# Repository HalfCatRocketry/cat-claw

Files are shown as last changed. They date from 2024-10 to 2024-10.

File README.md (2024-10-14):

Cat Claw is a cable cutter mechanism made of modified off-the-shelf commercially available parts. It is designed to be a low-cost and easy to service solution for parachute release to make single-compartment dual deployment recovery widely accessible.
Half Cat Rocketry provides the following:

• Component Guidebook (HCR-4100)

• SolidWorks CAD files (.sldprt)

• 3D models of printed components (.stl)

It is assumed that the reader is familiar with high-power rocketry and the use of basic hand tools.

Please note that the SolidWorks CAD was created in the version 2022 student edition and is for educational purposes.

Half Cat Rocketry is not liable for the usage of this content, and the authors bear no responsibility for the usage of its content. Read the following disclaimer before continuing.

DISCLAIMER:

By viewing, downloading, printing, or otherwise possessing the content in this repository you agree to the terms and conditions of its use, which are provided below. If you do not agree to the terms and conditions, you are required to remove this content from your possession by deleting all digital copies and/or disposing of printed materials in an environmentally responsible manner. Failure to do so shall constitute a violation of the license under which this content is distributed.

This content is provided as is, with absolutely NO WARRANTY, express or implied, including no warranty of merchantability or fitness for any particular purpose. You (“the user”) agree by your continued viewing or possession of this content to hold harmless and release from all liability the authors and any associated parties for any outcome resulting from your use or misuse of this material. The authors bear no responsibility for the usage of the this content, and any and all liability for injury, property damage, financial loss, death, or other harm arising from its use or misuse rests solely with the user.

This content is provided solely for informational and entertainment purposes and does not constitute an endorsement of, nor a recommendation to engage in, any particular activity, method, or practice. The information contained in this content solely represents the personal experiences of the authors and does not promise, guarantee, or predict any specific outcome of any particular activity, method, or practice.

The user acknowledges by continued viewing or possession of this content that rocketry and all associated activities, including but not limited to the procurement, manufacture, assembly, disassembly, modification, storage, handling, transport, operation, testing, launching, recovery and disposal of rocket and rocket motor systems, components, propellants, and accessories are inherently dangerous and may pose a direct and immediate hazard to health, life, and property.

Mentions of any particular products within this content by part number, name, description, brand, chemical formula, or any other identifier DO NOT constitute an endorsement of said products, nor is any warranty of merchantability or fitness for any particular purpose of said products expressed or implied by the authors of this content. Should the user purchase any product mentioned, listed, or otherwise discussed in this content, the user is solely responsible for determining the suitability of any and all products for the user’s specific application. The user is solely responsible for any outcome or liability arising from the use or misuse of any products named, described, or otherwise alluded to in this content.

As stated above, your (“the user’s”) continued viewing or possession of the content in this repository constitutes acknowledgement of and agreement to these warnings, terms, and conditions. If you do not agree to these terms and conditions, or do not wish to acknowledge the warnings provided herein, you are required to remove this content from your possession by deleting all digital copies and/or disposing of printed materials in an environmentally responsible manner. Failure to do so shall constitute a violation of the license under which this content is distributed.

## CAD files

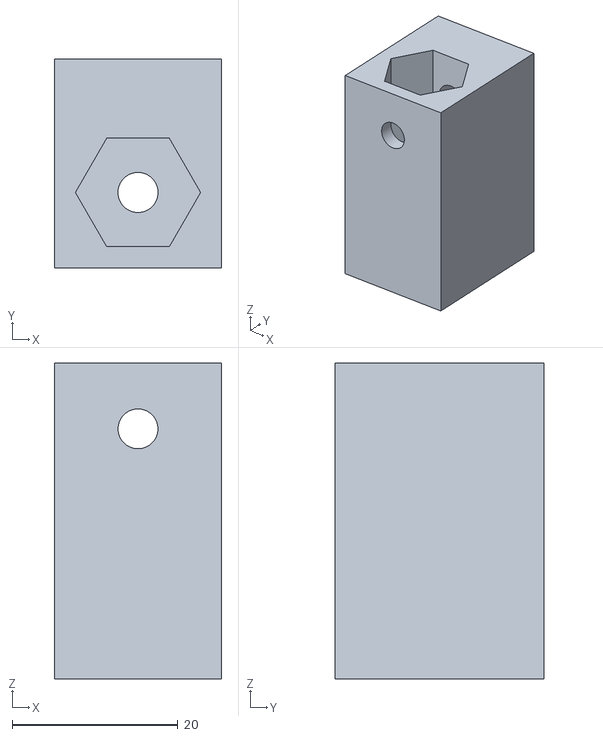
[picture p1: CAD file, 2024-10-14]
Printed Components/Cat Claw Drill Jig.STL
20.2 x 25.1 x 38.1

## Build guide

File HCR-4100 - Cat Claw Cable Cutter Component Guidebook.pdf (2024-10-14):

# Cat Claw Cable Cutter

# Component Guidebook

# HCR-4100

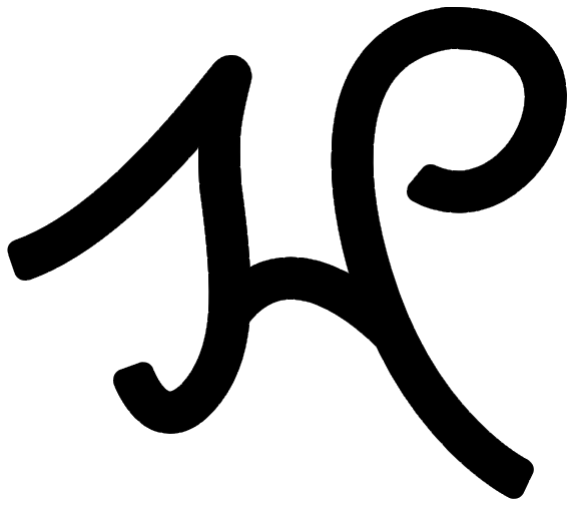
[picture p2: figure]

# Authored by Austin Sennott and Charles Sharp

# Warning

Rockets are dangerous! This publication is intended to provide information on the safe construction and operation of an amateur liquid rocket component, but it is no guarantee of safety. Always follow relevant safety guidelines and best practices when handling hazardous substances or situations – never assume that any situation is inherently safe.Half Cat Rocketry is not liable for the usage of this document, and the authors bear no responsibility for the usage of its content. Read the disclaimer on the next page before continuing.

# License

This guidebook, as well as all information within, is published open source under the GNU General Public License. See last page for more information.

# Attributions

The information contained herein is based upon publicly available content, including textbooks, scientific papers, government publications, and prior art.

All content in this document was written by humans, and not by AI.

Copyright 2024 Half Cat Rocketry

### READ THIS BEFORE CONTINUING

Disclaimer:

By downloading, printing, or otherwise possessing this content you agree to the terms and conditions of its use, which are provided below. If you do not agree to the terms and conditions, you are required to remove this content from your possession by deleting all digital copies and/or disposing of printed materials in an environmentally responsible manner. Failure to do so shall constitute a violation of the license under which this content is distributed.

This document is provided as is, with absolutely NO WARRANTY, express or implied, including no warranty of merchantability or fitness for any particular purpose. You (“the user”) agree by your continued possession of this document to hold harmless and release from all liability the authors and any associated parties for any outcome resulting from your use or misuse of this material. The authors bear no responsibility for the usage of the content of this document, and any and all liability for injury, property damage, financial loss, death, or other harm arising from its use or misuse rests solely with the user.

This document is provided solely for informational and entertainment purposes and does not constitute an endorsement of, nor a recommendation to engage in, any particular activity, method, or practice. The information contained in this document solely represents the personal experiences of the authors and does not promise, guarantee, or predict any specific outcome of any particular activity, method, or practice.

The user acknowledges by continued possession of this content that rocketry and all associated activities, including but not limited to the procurement, manufacture, assembly, disassembly, modification, storage, handling, transport, operation, testing, launching, recovery and disposal of rocket and rocket motor systems, components, propellants, and accessories are inherently dangerous and may pose a direct and immediate hazard to health, life, and property.

Mentions of any particular products within this document by part number, name, description, brand, chemical formula, or any other identifier DO NOT constitute an endorsement of said products, nor is any warranty of merchantability or fitness for any particular purpose of said products expressed or implied by the authors of this document. Should the user purchase any product mentioned, listed, or otherwise discussed in this document, the user is solely responsible for determining the suitability of any and all products for the user’s specific application. The user is solely responsible for any outcome or liability arising from the use or misuse of any products named, described, or otherwise alluded to in this document.

As stated above, your (“the user’s”) continued possession of this document constitutes acknowledgement of and agreement to these warnings, terms, and conditions. If you do not agree to these terms and conditions, or do not wish to acknowledge the warnings provided herein, you are required to remove this content from your possession by deleting all digital copies and/or disposing of printed materials in an environmentally responsible manner. Failure to do so shall constitute a violation of the license under which this content is distributed.

# About Half Cat Rocketry

Half Cat Rocketry began as a project to build a liquid bipropellant rocket in our final undergraduate semester at the University of Central Florida. From September through December 2020, we constructed, iterated, and finally test fired Half Cat Walking. From participating in introductory rocket projects, to leading them, to producing solid motors, to designing hybrid systems, four years of learning culminated in four months of innovation and success.

We are Austin Sennott and Charles Sharp. For eight years, we have been relentlessly gaining experience in amateur rocketry, woven together with education and careers in aerospace engineering. Today, our focus is on pioneering simple, reliable liquid rocket motors and supporting students and individuals looking to build their own. Our goal is to demonstrate that they can be accomplished quickly and economically, for the benefit of both the hobby and the careers of students everywhere. We were once students ourselves, and still produce rockets with our own time and money, so we are well acquainted with the need to reduce scope and budget as much as possible.

Half Cat is the name of a meme, unique and recognizable. We do serious work, but we don't take ourselves too seriously - our brand and project names are a lighthearted nod to the industry, which can too often lack originality.

Half Cat Rocketry is ongoing, and we will continue to build rockets and publish

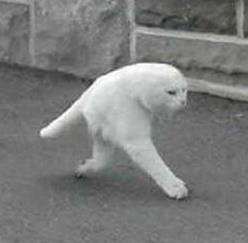
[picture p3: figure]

information about them. Our hope is to redefine what's possible for students and amateurs to achieve with a little bit of creativity, leading the way for ever more awesome projects.

# About the Authors

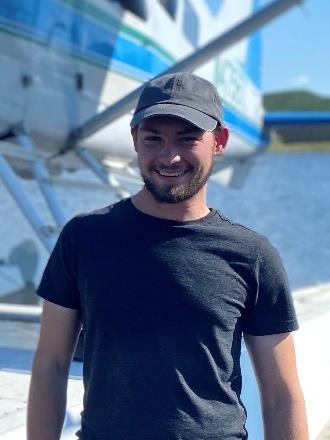
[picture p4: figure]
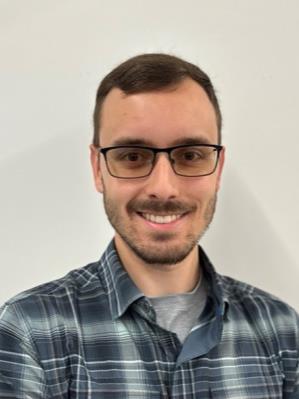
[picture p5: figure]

Austin Sennottis a
rocket propulsion
engineer and Level 2
certified in high-power
rocketry. Since 2018, he
has been building
experimental solid,
hybrid, and liquid
motors, including the
first liquid bipropellant
rocket fired at UCF.

LinkedIn (https://www.linkedin.com/in/austinsennott/)

Charles Sharp is Level
3 certified in high-power
rocketry and employed
as a rocket propulsion
engineer. In over 10 years of building rockets, he
has gained expertise in
all types of rocket
propulsion, including the
first high-power rocket
propelled by liquid CO2.

LinkedIn (https://www.linkedin.com/in/charlessharpengineer/)

## CAT CLAW | Component Guidebook | HCR-4100

Half Cat Rocketry
HalfCatRocketry.com
contact@halfcatrocketry.com

# Version History

Revision | Description | Date
01 | Initial Release | 14 Oct 2024

The latest version may be found on both the Half Cat Rocketry website and GitHub repository:

Half Cat Rocketry Website (https://www.halfcatrocketry.com/cat-claw)

GitHub Repository (https://github.com/HalfCatRocketry/cat-claw)

# Scope

Cat Claw is a cable cutter mechanism made of modified off-the-shelf commercially available parts. It is designed to be a low-cost and easy to service solution for parachute release to make single-compartment dual deployment recovery widely accessible.

This guidebook covers:

- Background on the function of cable cutters
- Parts list and assembly instructions
- Manufacturing reference materials

It is assumed that the reader is familiar with high-power rocketry and the use of basic hand tools.

# Table of Contents

1

# Introduction

### What is a cable cutter and how does it work?

Cable cutters are used as an alternative to conventional dual deployment recovery in amateur rockets. Rather than deploying the drogue and main from separate compartments in the airframe, with cable cutters both the drogue and main parachute are ejected at apogee from a single airframe separation point. The main parachute is kept tightly bundled by a nylon cable tie, which the cable cutter severs to release at the desired deployment altitude during descent. This allows for a more compact airframe and recovery system, without the need for shear pins.

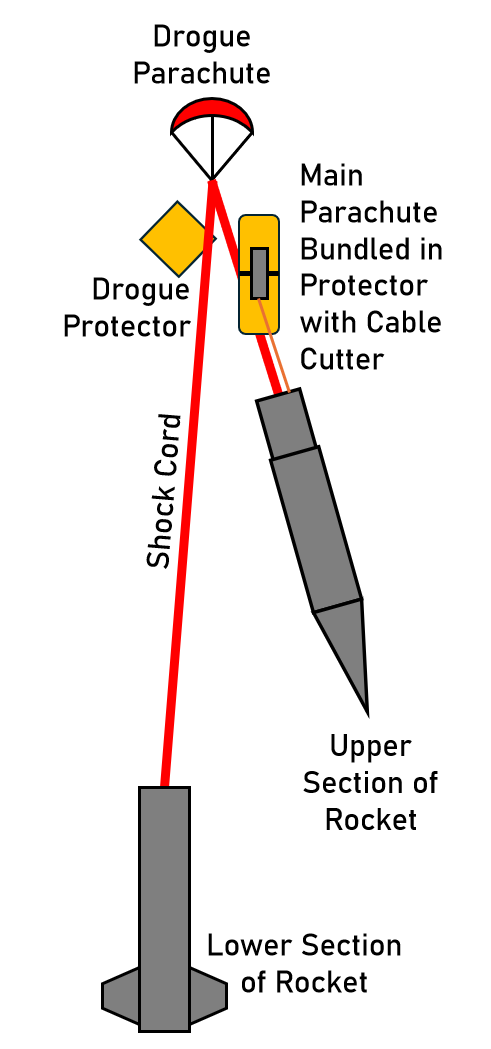
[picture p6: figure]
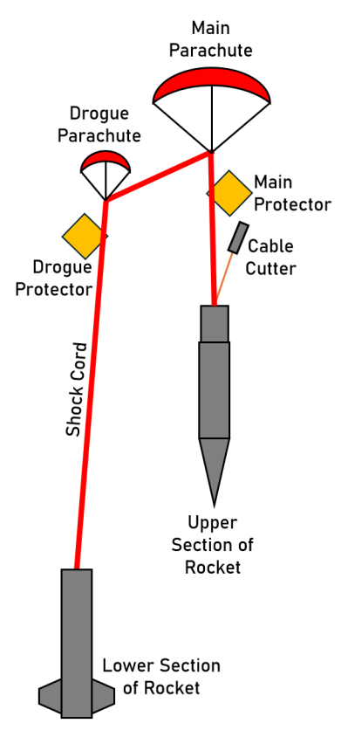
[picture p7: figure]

Cable cutters shear the cable tie which bundles the main parachute, using a metal piston propelled by a small pyrotechnic charge. The charge is ignited by an electronic match which receives current from an electronic deployment controller, just like a typical pyrotechnic deployment charge. When using cable cutters for main deployment, standard pyrotechnic deployment charges are used for the apogee separation event.

2

### Cat Claw Cable Cutter

Cat Claw is not the most compact or lightweight cable cutter, but it is intended to be the most accessible option. There are other, smaller designs, but Cat Claw can be made very cheaply in-house by any hobbyist. Furthermore, it is easy to load and reuse quickly which minimizes the labor involved in preparing a rocket for flight. Cable cutters already find use in high-power rocketry, but this document is intended to make them a less difficult and more practical option for single-compartment dual deployment recovery on all but the most mass-optimized rockets.

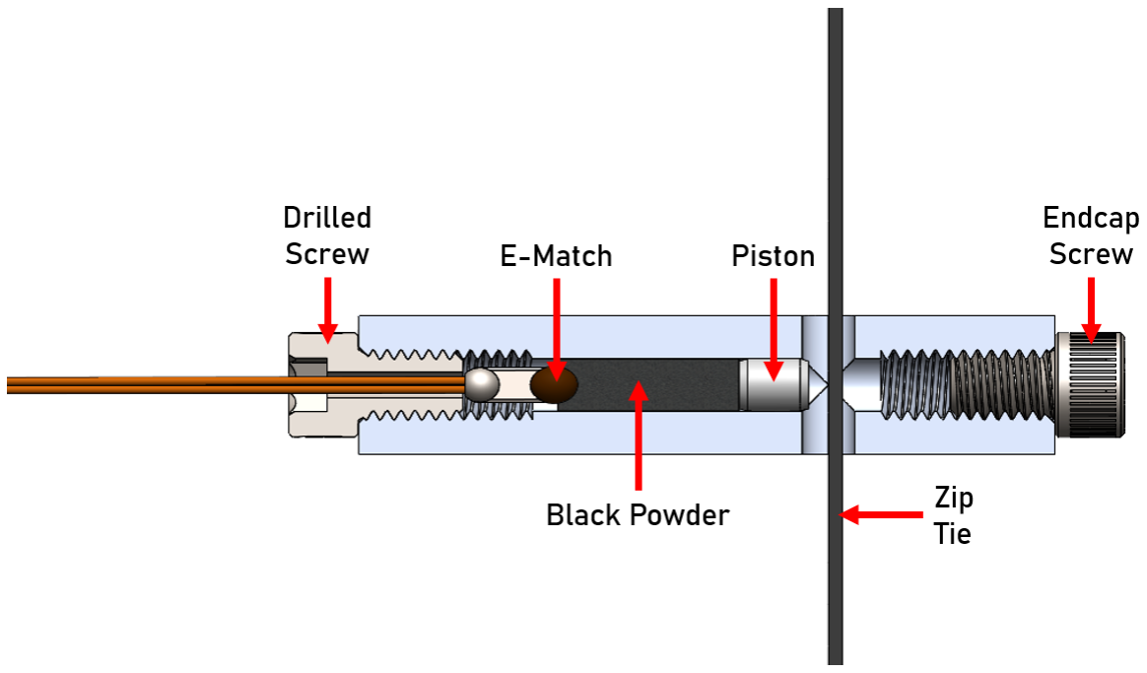
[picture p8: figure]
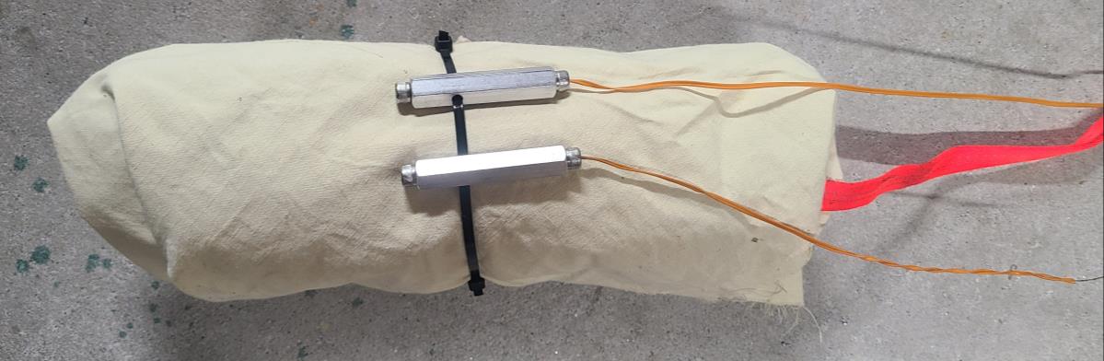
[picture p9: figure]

3

# Bill of Materials

This Bill of Materials (BOM) produces a set of two Cat Claws at a cost of $17.13 each. However, some line items are multi-packs and producing additional cable cutters will reduce the per-unit cost. Additionally, the tools are a fixed cost and only need to be purchased once.

It is assumed that a standard consumer-grade 3D-printer is available for making the printed components. While they are not strictly necessary, the drill jig makes fabrication of the cable cutter body very easy and extremely quick, and the scoop and funnel makes loading a simple and deterministic process.

## Components

Line | Item | Unit Price | QTY | Cost | Context
| Female Threaded Hex Standoff,
1

Aluminum, 1/2" Hex, 2-1/2" Long, 1/4"-
20 Thread
| $5.91 | 2 | $11.82 | Cable Cutter Body

2

18-8 Stainless Steel Dowel Pin, 3/16"
Diameter, 1/4" Long, Pack of 20 | $5.42 | 1 | $5.42 | Cable Cutter Piston

3

Vented Socket Head Screw, 1/4"-20
Thread Size, 3/8" Long, Pack of 5 | $7.03 | 1 | $7.03 | Cable Cutter End Caps
| Subtotal | | $24.27
Note: If producing >2X units, 93235A534 (Line 3) may be substituted with 92185A535 for the non-e-match side
Line | Part Number | Vendor Description | Source
| | Female Threaded Hex Standoff
1 91780A363
Aluminum, 1/2" Hex, 2-1/2" Long, 1/4"-20 Thread

https://www.mcmaster.com/91780A363/

2 | 90145A501 | 18-8 Stainless Steel Dowel Pin
3/16" Diameter, 1/4" Long | https://www.mcmaster.com/90145A501/
3 | 93235A534 | Vented Socket Head Screw
1/4"-20 Thread Size, 3/8" Long | https://www.mcmaster.com/93235A534/

4

| 92185A535 (if producing >2X units) | Super-Corrosion-Resistant 316 Stainless Steel Socket Head Screw 1/4"-20 Thread Size, 3/8" Long
https://www.mcmaster.com/92185A535/

4

## Tools

Line | Item | Unit Price | QTY | Cost | Context
| Short-Length Drill Bit, TiN-Coated
1

High-Speed Steel, 3/32" Size, 1-3/4"
Overall Length
$3.51 | 1 | $3.51 | Drill Bit for E-match Hole

2

Uncoated High-Speed Steel Drill Bit,

12 Gauge Size, 3-1/2" Overall Length | $2.35 | 1 | $2.35 | Drill Bit for Zip Tie &
| | | | Piston Holes

3

Loop Handle Tube Brush, Low-
Scratch Brass Bristles, 3/16" Diameter, 7" Overall Length | $3.30 | 1 | $3.30 | Cleaning Brush

4

Hex L-Key, with Standard Tip, 9/64"
Size, 4-1/16" Overall Length | $0.41 | 1 | $0.41 | Piston Removal Tool

5

Hex L-Key, with Standard Tip, 3/16"
Size, 2-15/16" Overall Length | $0.41 | 1 | $0.41 | Socket Screw Hex Key
| Subtotal | | $9.98
Line | Part Number | Vendor Description | Source
1 | 2908A33 | Short-Length Drill Bit, TiN-Coated High-Speed
Steel, 3/32" Size, 1-3/4" Overall Length | https://www.mcmaster.com/2908A33/
2 | 30585A23 | Uncoated High-Speed Steel Drill Bit
12 Gauge Size, 3-1/2" Overall Length | https://www.mcmaster.com/30585A23/
3 | 7353T518 | Loop Handle Tube Brush, Low-Scratch Brass
Bristles, 3/16" Diameter, 7" Overall Length | https://www.mcmaster.com/7353T518/
4 | 7122A45 | Hex L-Key with Standard Tip, 9/64" Size, 4-1/16"
Overall Length | https://www.mcmaster.com/7122A45/
5 | 7122A22 | Hex L-Key with Standard Tip, 3/16" Size, 2-
15/16" Overall Length | https://www.mcmaster.com/7122A22/

## Consumables

Line | Item | Unit Price | QTY | Cost | Context
1 | Nylon Zip Ties, 3/16" Wide Max | Variable | - | - | Securing Parachute

2

3F Pyrodex Powder or 4F Black
Powder
| | Variable | - | - | Pyrotechnic Charge
3 | E-matches | Variable | 1 | - | Cable Cutter Initiation

5

## Printed Components

Line | Item | Unit Price | QTY | Cost | Context
1 | McMaster Cable Cutter Drill Jig.STL | $0.00 | 1 | $0.00 | Printed
2 | Cable Cutter Powder Scoop.STL | $0.00 | 1 | $0.00 | Printed
3 | Cable Cutter Powder Funnel.STL | $0.00 | 1 | $0.00 | Printed

## Print Orientation

Print components in the following orientations:

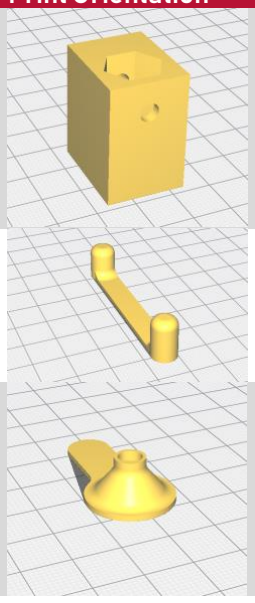
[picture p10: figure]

Part Number | Print Orientation

Cat Claw Drill Jig.STL

Cable Cutter Powder Scoop.STL

Cable Cutter Powder Funnel.STL

6

# Fabrication Procedure

### Required Tools

QTY | Tool
1 Power Drill

### 1 Bench Vise

1 3/32” Drill Bit
1 #12 Drill Bit

### 1 Cat Claw Drill Jig

1. Insert the 91780A363 hex standoff into the printed drill jig as shown, until it fully bottoms out. If it is a loose fit, apply tape to the hex standoff as needed until snug.

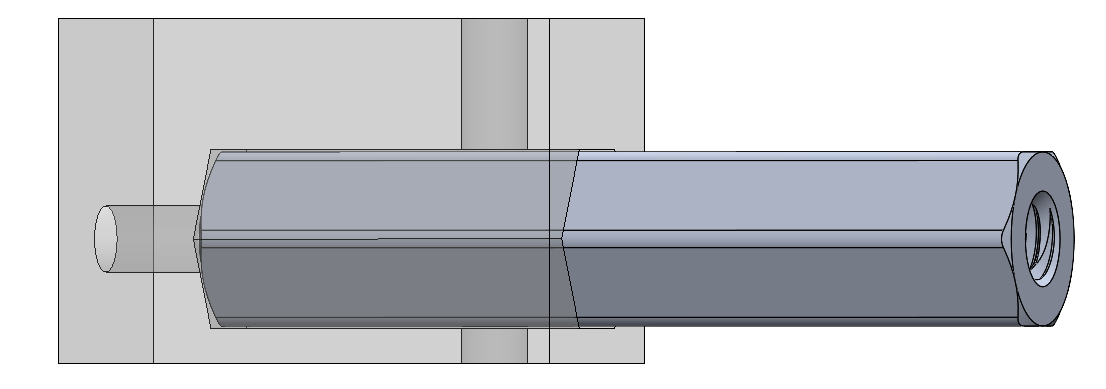
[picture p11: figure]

2. Clamp the drill jig in a bench vise with the longer side of the zip tie hole guide facing upwards. Using the #12 drill bit, drill the zip tie hole through the hex standoff as shown.

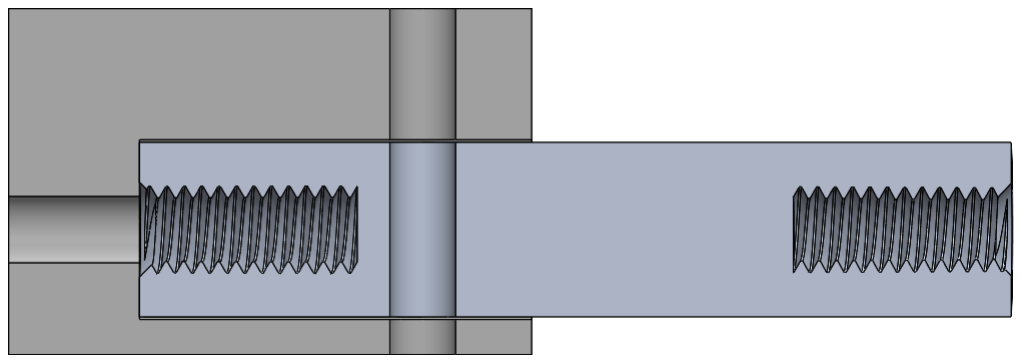
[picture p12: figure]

7

3. Clamp the hex standoff directly in the bench vise, with the piston bore end of the drill jig facing upwards. Using the #12 drill bit, drill the piston bore until it connects the two threaded holes as shown. Clean out any drill chips and/or cutting oil.

Note: Do not clamp the printed drill jig for this step, or the hex standoff will be pushed out of the jig by the drill bit.

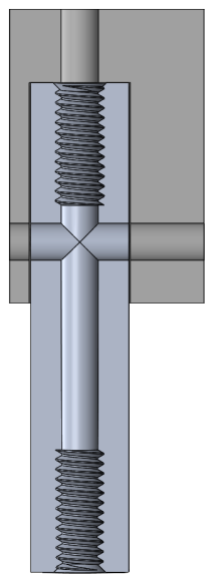
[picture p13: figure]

4. Remove the hex standoff from the printed drill jig, and install QTY 1 93235A534 vented screw hand-tight into the end farther from the zip tie hole as shown. Clamp the hex standoff in the bench vise with the head of the screw facing up. Apply WD-40 or cutting oil to the 3/32” drill bit, and drill out the existing vent hole as shown. This will allow the e-match wires to pass through the screw. Remove the screw and clean out any drill chips and/or cutting oil.

Note: Only one screw needs to be drilled out per cable cutter. The screw on the opposite side may remain unmodified.

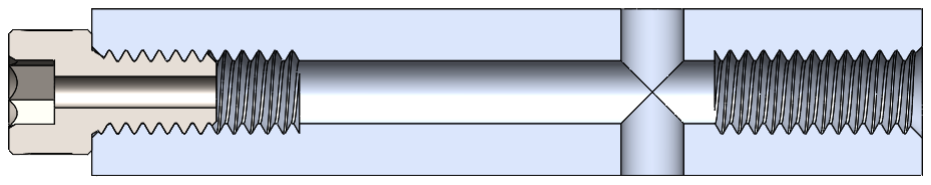
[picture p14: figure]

8

# Assembly and Loading Procedure

1. Assemble and load the cable cutter:
a. Test e-match for continuity, then insert twisted wire leads through the drilled-out 93235A534 screw from the end and out through the socket. A small strip of masking or electrical tape around the solder beads at the base of the e-match head is recommended to prevent shorting and/or powder leakage.
b. Install un-modified 93235A534 (or 92185A535) screw into the threaded end closer to the zip tie hole and tighten to snug using the 3/16” hex key.
c. Insert the zip tie (3/16” wide max.) through the zip tie hole. Place a small piece of masking tape on the tail of the zip tie to prevent it from falling out.
d. Insert the 90145A501 piston into the bore from the end farther from the zip tie hole. Use the 9/32” hex key to ensure it is all the way down the bore, contacting the zip tie.
e. Measure out 3F black powder replacement (Pyrodex P or equivalent) or 4F black powder (Goex FFFF or equivalent) using the appropriately labeled end of the printed powder scoop.
f. Pour the powder into the cable cutter on top of the piston, using the printed powder loading funnel
g. Install the drilled-out 93235A534 screw with e-match into the threaded end farther from the zip tie hole and tighten to snug.

Optional: Tie a thin Kevlar cord around the base of the screw head before running down fully, to provide more secure retention of the table cutter than the wires alone.

h. After folding the parachute and wrapping with a flame-proof protector, cinch the zip tie around the parachute bundle. For redundancy, it is recommended to use two cable cutters, which must either be on the same zip tie, or zip ties that are daisy chained together. Do not place multiple independent zip ties around the parachute.
i. Connect the e-match wires to the Main charge leads from the deployment controller just as you would an ejection charge. Ensure the connections are mechanically secure and insulated from one another. The main parachute bundle is now ready to pack inside the rocket airframe.

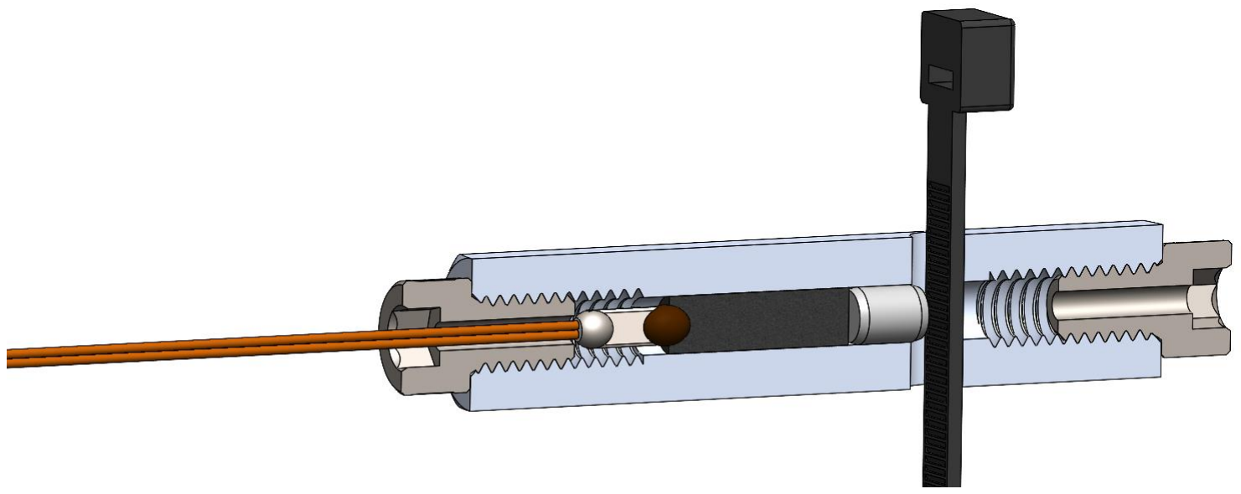
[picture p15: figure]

9

2. Post-Recovery Servicing:
a. Remove both screws from the hex standoff and push out the piston using the 9/32” hex key. A small section of the zip tie may also remain inside the cable cutter, and must be removed.
b. Remove the spent e-match from the drilled-out screw.
c. Clean the piston bore and piston of residue using the 7353T518 brush. If using water or other solvents, ensure the interior of the cable cutter is fully dry before reloading.

10

# License and Copyright Information

Copyright 2024 Half Cat Rocketry

Half Cat Rocketry is dedicated to expanding the knowledge of liquid rockets in the amateur community by freely sharing our designs, experience, and data publicly. Therefore, all works released by Half Cat Rocketry are published under the GNU General Public License (GNU GPL). Although primarily intended for software, the terms of the GNU GPL capture the spirit of Half Cat Rocketry.

The work of Half Cat Rocketry is presented for free; you can redistribute and/or modify any designs or software under the terms of the GNU General Public License as published by the Free Software Foundation; either version 3 of the License, or (at your option) any later version.

This work is distributed in the hope that it will be useful, but WITHOUT ANY WARRANTY; without even the implied warranty of MERCHANTABILITY or FITNESS FOR A PARTICULAR PURPOSE. See the GNU General Public License (below) for more details.

Additional permission under GNU GPL version 3 section 7:

Any publication of designs, work, or derivative work originated by Half Cat Rocketry, in part or in whole, must be attributed to Half Cat Rocketry. Furthermore, any publication of such work must be made freely available under the GNU GPL version 3.

Half Cat Rocketry is not liable for any aspect of the interpretation or implementation of its work in any capacity. By using this document, or anything distributed by Half Cat Rocketry in any form, you release the licensors from any and all liability arising from your usage.

Link to Half Cat Rocketry Website (https://www.halfcatrocketry.com/copyright)

Link to GNU GPL Version 3 (HCR GitHub repository) (https://github.com/HalfCatRocketry/cat-claw)

Link to GNU GPL Version 3 (Free Software Foundation) (https://www.gnu.org/licenses/gpl-3.0.html)
